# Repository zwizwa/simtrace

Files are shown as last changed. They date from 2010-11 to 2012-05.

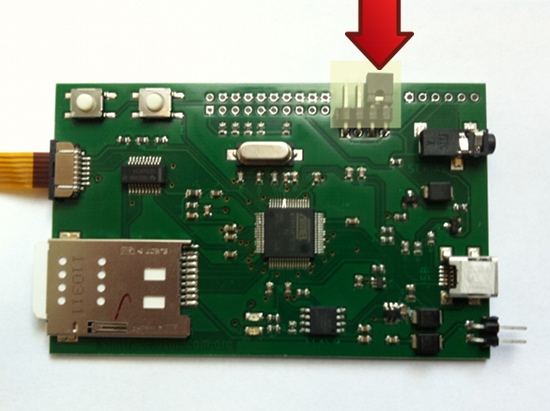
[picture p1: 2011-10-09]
docs/images/shortTEST.jpg

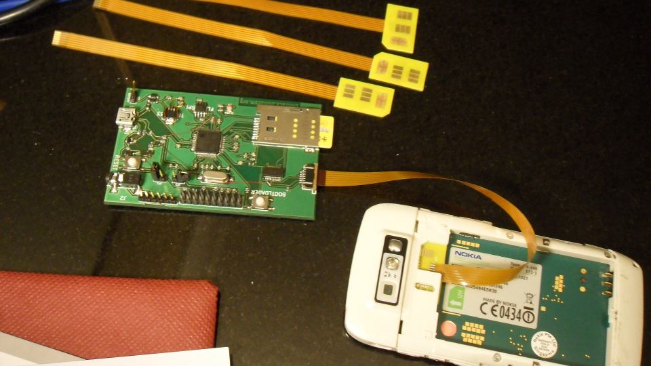
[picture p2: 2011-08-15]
docs/images/simtrace_hw_setup.png

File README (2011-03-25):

Osmocom SIMTRACE
======================================================================
(C) 2010 by Harald Welte <laforge@gnumonks.org>

SIMTRACE is a program that can be used for tracing the communication
betewen a phone and the SIM card.  More generally, it can trace any
ISO 7816 based smart card interface.

This repository contains a host program 'simtrace' as well as a patch
for wireshark.

The corresponding device firmware can be found in the openpcd.git
repository on git.gnumonks.org.

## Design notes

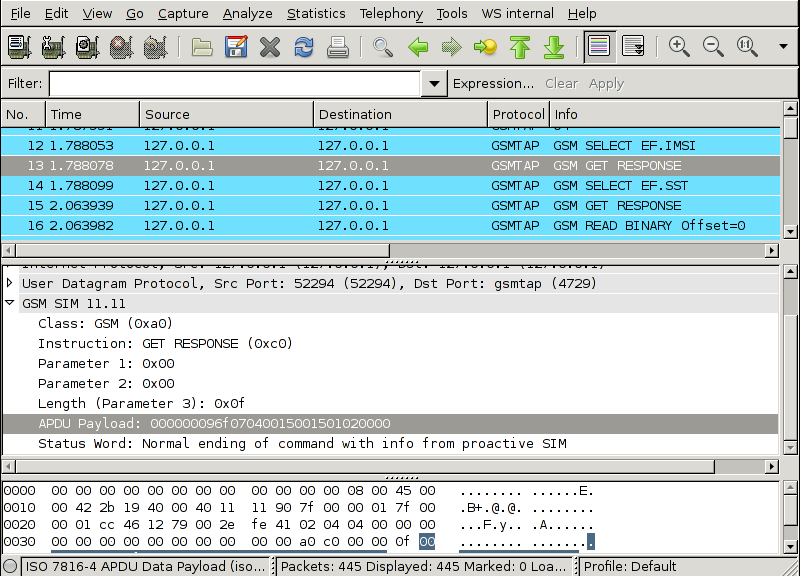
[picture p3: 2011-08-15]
docs/images/wireshark-sim.png

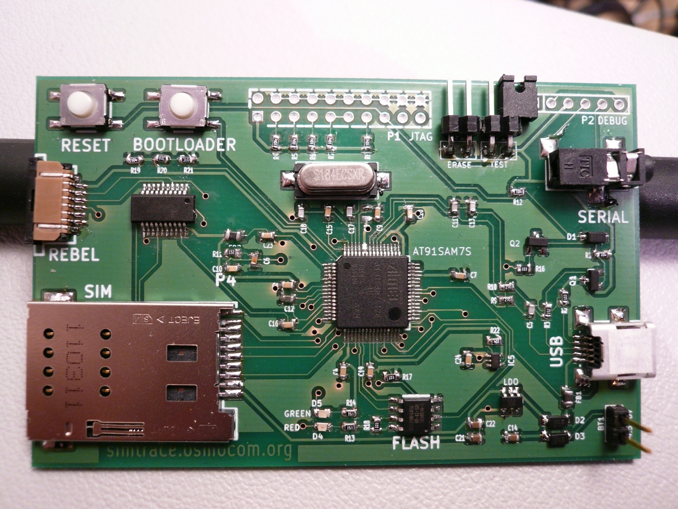
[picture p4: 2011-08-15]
docs/images/simtrace_hw.jpg

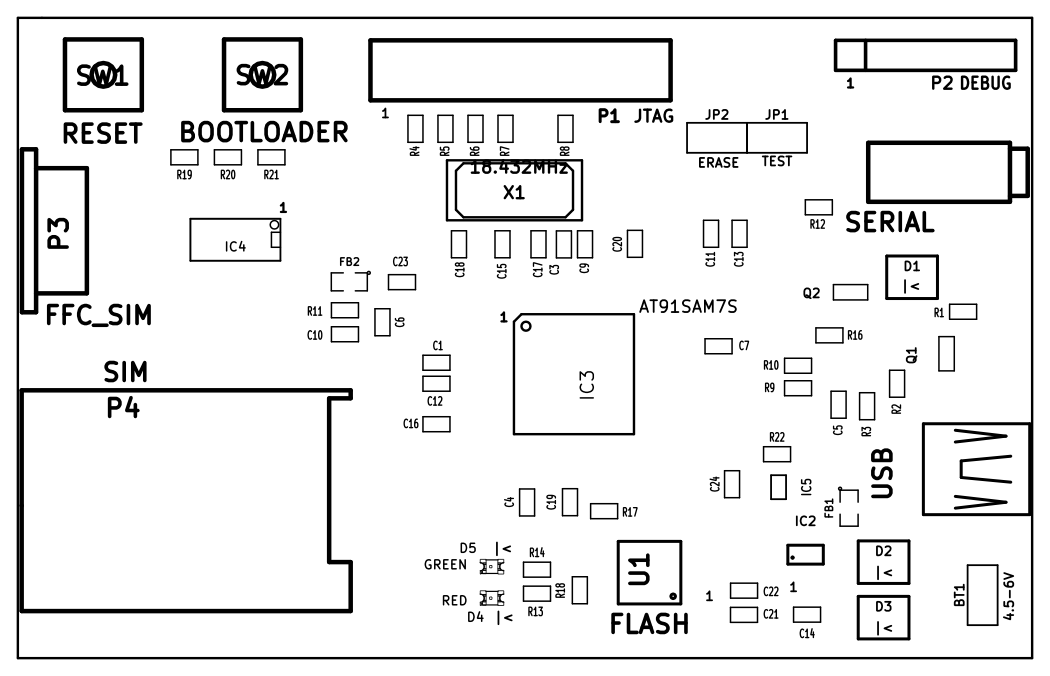
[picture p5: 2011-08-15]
docs/images/simtrace_surface.png

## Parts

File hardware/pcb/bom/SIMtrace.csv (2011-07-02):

Id | Designator | Package | Quantity | Designation | Supplier and ref
1 | P3 | FFC_REBELSIM | 1 | FFC_SIM
2 | P1 | pin_array_10x2 | 1 | JTAG
3 | JP2 | PIN_ARRAY_2X1 | 1 | ERASE
4 | JP1 | PIN_ARRAY_2X1 | 1 | TEST
5 | BT1 | PIN_ARRAY_2X1 | 1 | 4.5-6V
6 | X1 | Q_49U3HMS | 1 | 18.432MHz
7 | R18,R17,R16,R2 | SM0603 | 4 | 10K
8 | R14,R13 | SM0603 | 2 | 150R
9 | R12,R8,R7,R6,R5,R4,R1,R22,R19 | SM0603 | 9 | 100K
10 | R11,R3 | SM0603 | 2 | 1K5
11 | R10,R9 | SM0603 | 2 | 27R
12 | C23,C20,C19,C16,C15,C9,C7,C4,C3,C24 | SM0603 | 10 | 100nF
13 | C22,C21,C14 | SM0603 | 3 | 1uF
14 | C18,C17 | SM0603 | 2 | 10pF
15 | C13,C11 | SM0603 | 2 | 15pF
16 | C12,C1 | SM0603 | 2 | 2.2uF
17 | C10 | SM0603 | 1 | 1nF
18 | C6 | SM0603 | 1 | 10nF
19 | C5 | SM0603 | 1 | 33pF
20 | FB2,FB1 | SM0805 | 2 | FILTER
21 | D3,D2 | SOD123 | 2 | 1N5819
22 | D1 | SOD123 | 1 | Schottky
23 | U1 | SOIC8 | 1 | FLASH
24 | IC3 | TQFP_64 | 1 | AT91SAM7S
25 | P2 | PIN_ARRAY-6X1 | 1 | DEBUG
26 | Q2,Q1 | SOT23_BC847 | 2 | BC847
27 | SW1 | PUSH_BUTTON | 1 | RESET
28 | SW2 | PUSH_BUTTON | 1 | BOOTLOADER
29 | P4 | SIM_AMPHENOL | 1 | SIM
30 | IC4 | SSOP20_BDQ | 1 | CB3Q3244
31 | R21,R20 | SM0603 | 2 | 10k1%
32 | IC5 | SOT353 | 1 | FPF2005
33 | IC2 | SOT26 | 1 | AP7332
34 | P5 | SAM_FCI | 1 | SAM
35 | J2 | JACK2.5_SJ1-2503A | 1 | JACK_2.5
36 | J1 | USB-MINI-B_54819-0519 | 1 | USB
37 | D5 | LED-0805 | 1 | GREEN
38 | D4 | LED-0805 | 1 | RED

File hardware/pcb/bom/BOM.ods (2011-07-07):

Id | Designator | Package | Quantity | Designation | digikey ref | link
1 | P3 | FFC_REBELSIM | 1 | FFC_SIM | 609-1889-1-ND | click me
2 | P1 | pin_array_10x2 | 1 | JTAG
3 | JP2 | PIN_ARRAY_2X1 | 1 | ERASE
4 | JP1 | PIN_ARRAY_2X1 | 1 | TEST
5 | BT1 | PIN_ARRAY_2X1 | 1 | 4.5-6V
6 | X1 | Q_49U3HMS | 1 | 18.432MHz | XC1252CT-ND | click me
7 | R18,R17,R16,R2 | SM0603 | 4 | 10K | RMCF0603JT10K0CT-ND | click me
8 | R14,R13 | SM0603 | 2 | 150R | P150GCT-ND | click me
9 | R12,R8,R7,R6,R5,R4,R1,R22,R19 | SM0603 | 9 | 100K | P100KGCT-ND | click me
10 | R11,R3 | SM0603 | 2 | 1K5 | RMCF0603JT1K50CT-ND | click me
11 | R10,R9 | SM0603 | 2 | 27R | P27GCT-ND | click me
12 | C23,C20,C19,C16,C15,C9,C7,C4,C3,C24 | SM0603 | 10 | 100nF | 478-1239-1-ND | click me
13 | C22,C21,C14 | SM0603 | 3 | 1uF | 490-1543-1-ND | click me
14 | C18,C17 | SM0603 | 2 | 10pF | 490-1403-1-ND | click me
15 | C13,C11 | SM0603 | 2 | 15pF | 709-1142-1-ND | click me
16 | C12,C1 | SM0603 | 2 | 2.2uF | 478-6212-1-ND | click me
17 | C10 | SM0603 | 1 | 1nF | 478-1215-1-ND | click me
18 | C6 | SM0603 | 1 | 10nF | 490-1512-1-ND | click me
19 | C5 | SM0603 | 1 | 33pF | 490-1415-1-ND | click me
20 | FB2,FB1 | SM0805 | 2 | FILTER | P10191CT-ND | click me
21 | D3,D2 | SOD123 | 2 | 1N5819 | 1N5819HW-FDICT-ND | click me
22 | D1 | SOD123 | 1 | Schottky | MBR0530T1GOSCT-ND | click me
23 | U1 | SOIC8 | 1 | FLASH | SST25VF040B-80-4I-SAE-ND | click me
24 | IC3 | TQFP_64 | 1 | AT91SAM7S | AT91SAM7S128C-AU-ND | click me
25 | P2 | PIN_ARRAY-6X1 | 1 | DEBUG
26 | Q2,Q1 | SOT23_BC847 | 2 | BC847 | BC847CINCT-ND | click me
27 | SW1 | PUSH_BUTTON | 1 | RESET | P12943SCT-ND | click me
28 | SW2 | PUSH_BUTTON | 1 | BOOTLOADER | P12943SCT-ND | click me
29 | P4 | SIM_AMPHENOL | 1 | SIM | 101-00271-82-1-ND | click me
30 | IC4 | SSOP20_BDQ | 1 | CB3Q3244 | 296-19125-1-ND | click me
31 | R21,R20 | SM0603 | 2 | 10k1% | 311-10.0KHRCT-ND | click me
32 | IC5 | SOT353 | 1 | FPF2005 | FPF2005CT-ND | click me
33 | IC2 | SOT26 | 1 | AP7332 | AP7332-3333W6-7DICT-ND | click me
34 | P5 | SAM_FCI | 1 | SAM | 609-1414-ND | click me
35 | J2 | JACK2.5_SJ1-2503A | 1 | JACK_2.5 | CP1-2503A-ND | click me
36 | J1 | USB-MINI-B_54819-0519 | 1 | USB | WM17115-ND | click me
37 | D5 | LED-0805 | 1 | GREEN | 475-1410-1-ND | click me
38 | D4 | LED-0805 | 1 | RED | 350-2038-1-ND | click me
additional
 | FFC |  | 4 |  | WM10052-ND | click me
 | jumper |  | 2 |  | S9337-ND | click me
 | pin array 90° |  | 1 |  | S1112E-36-ND | click me

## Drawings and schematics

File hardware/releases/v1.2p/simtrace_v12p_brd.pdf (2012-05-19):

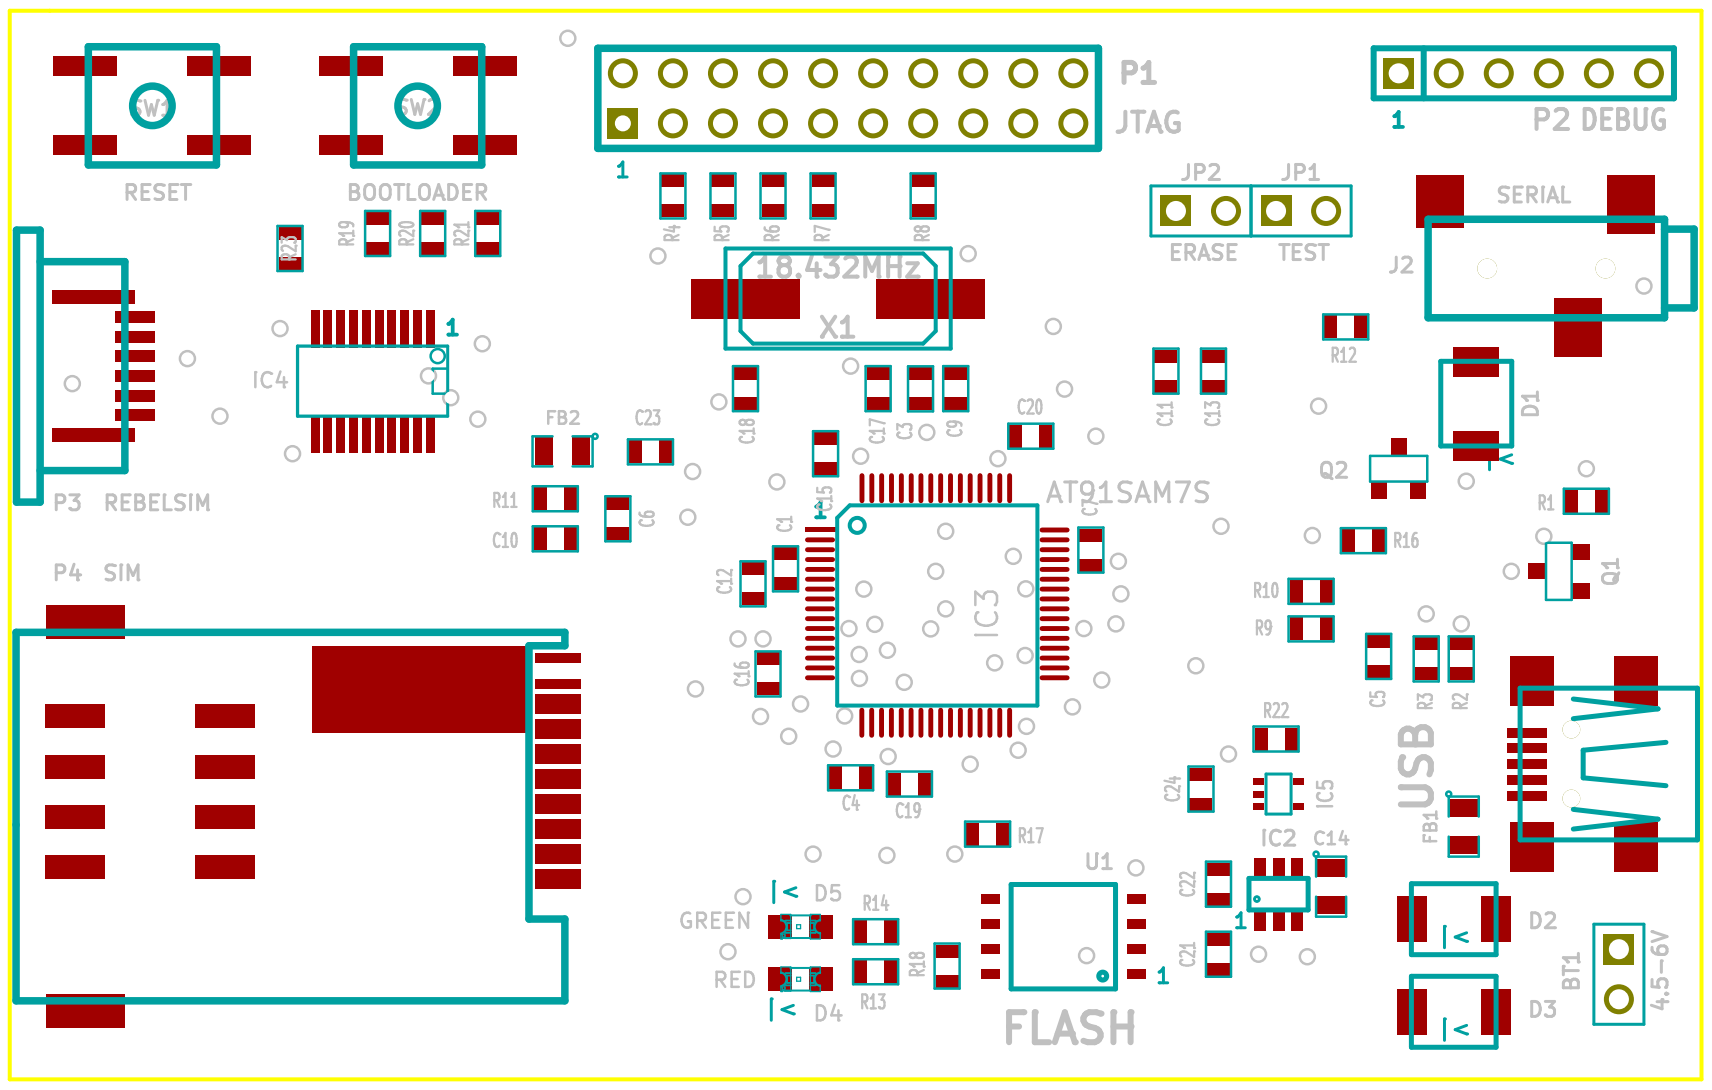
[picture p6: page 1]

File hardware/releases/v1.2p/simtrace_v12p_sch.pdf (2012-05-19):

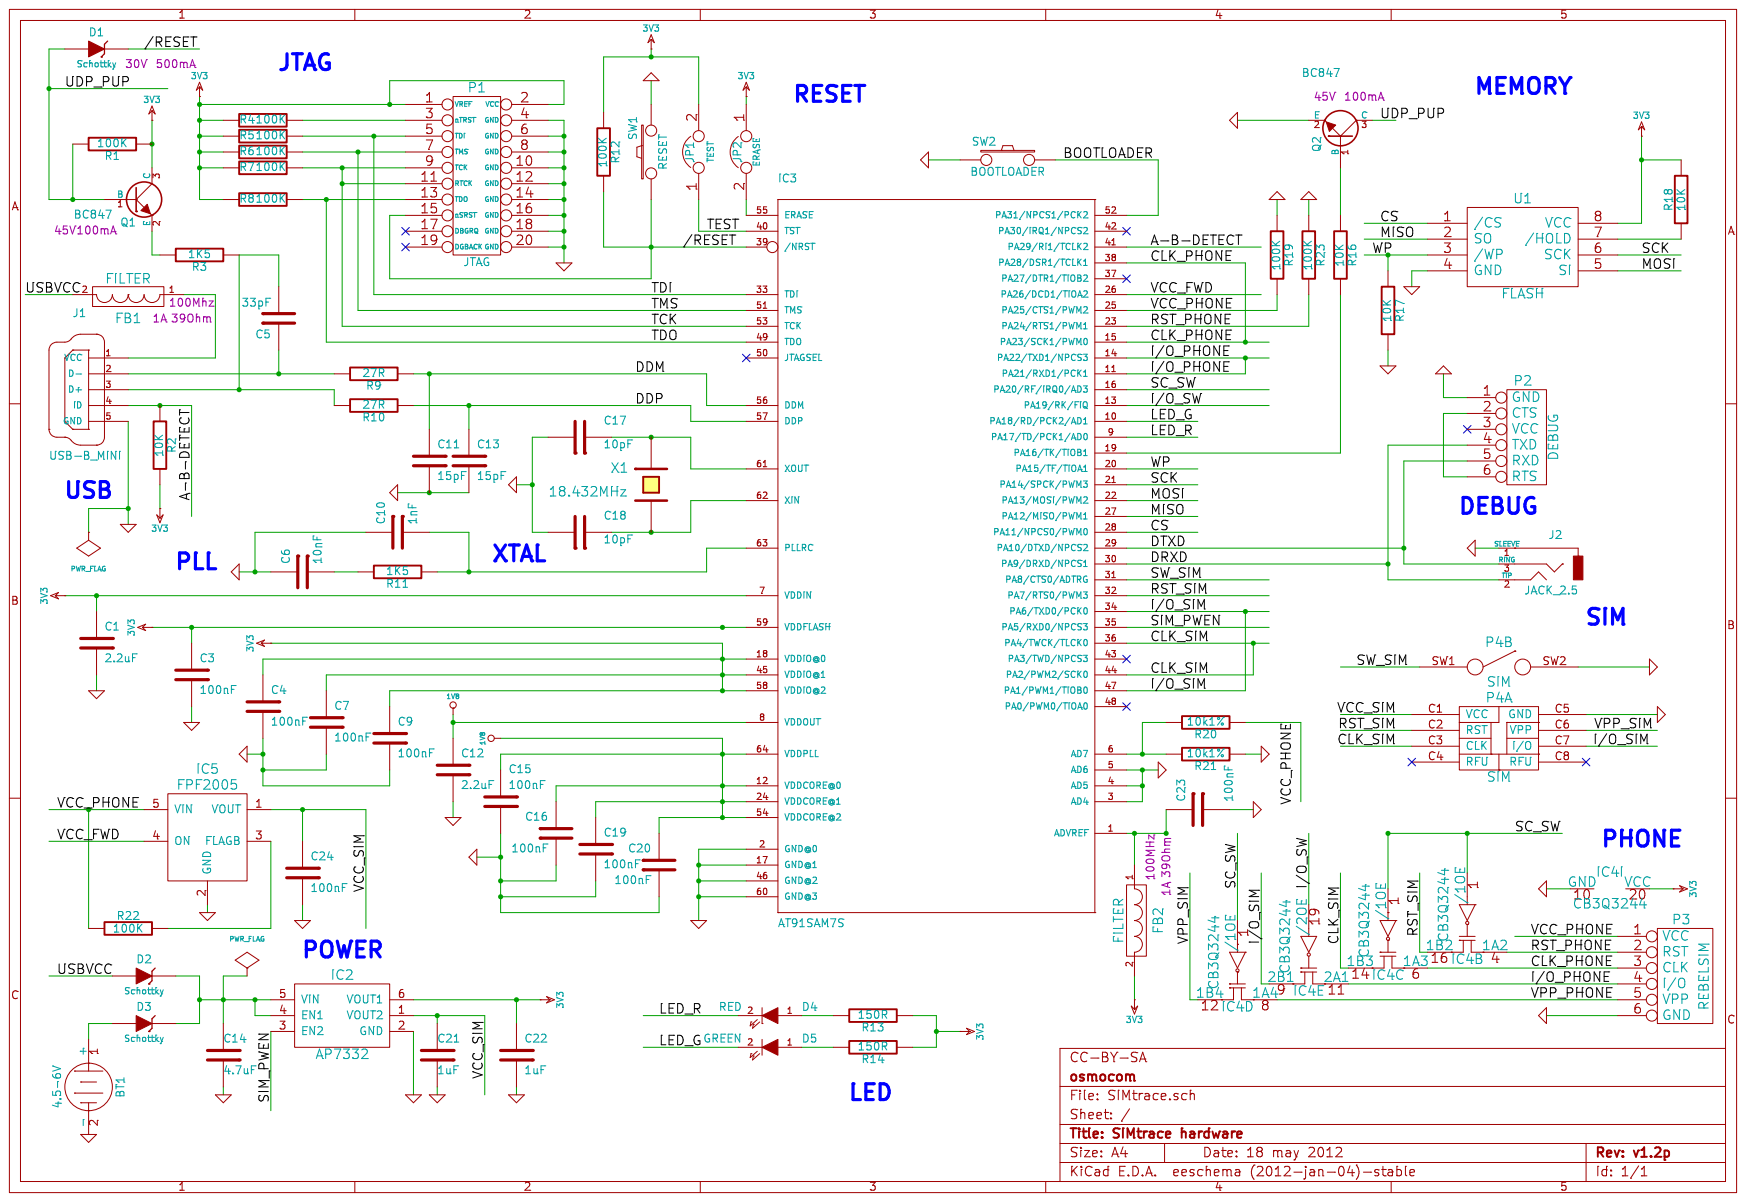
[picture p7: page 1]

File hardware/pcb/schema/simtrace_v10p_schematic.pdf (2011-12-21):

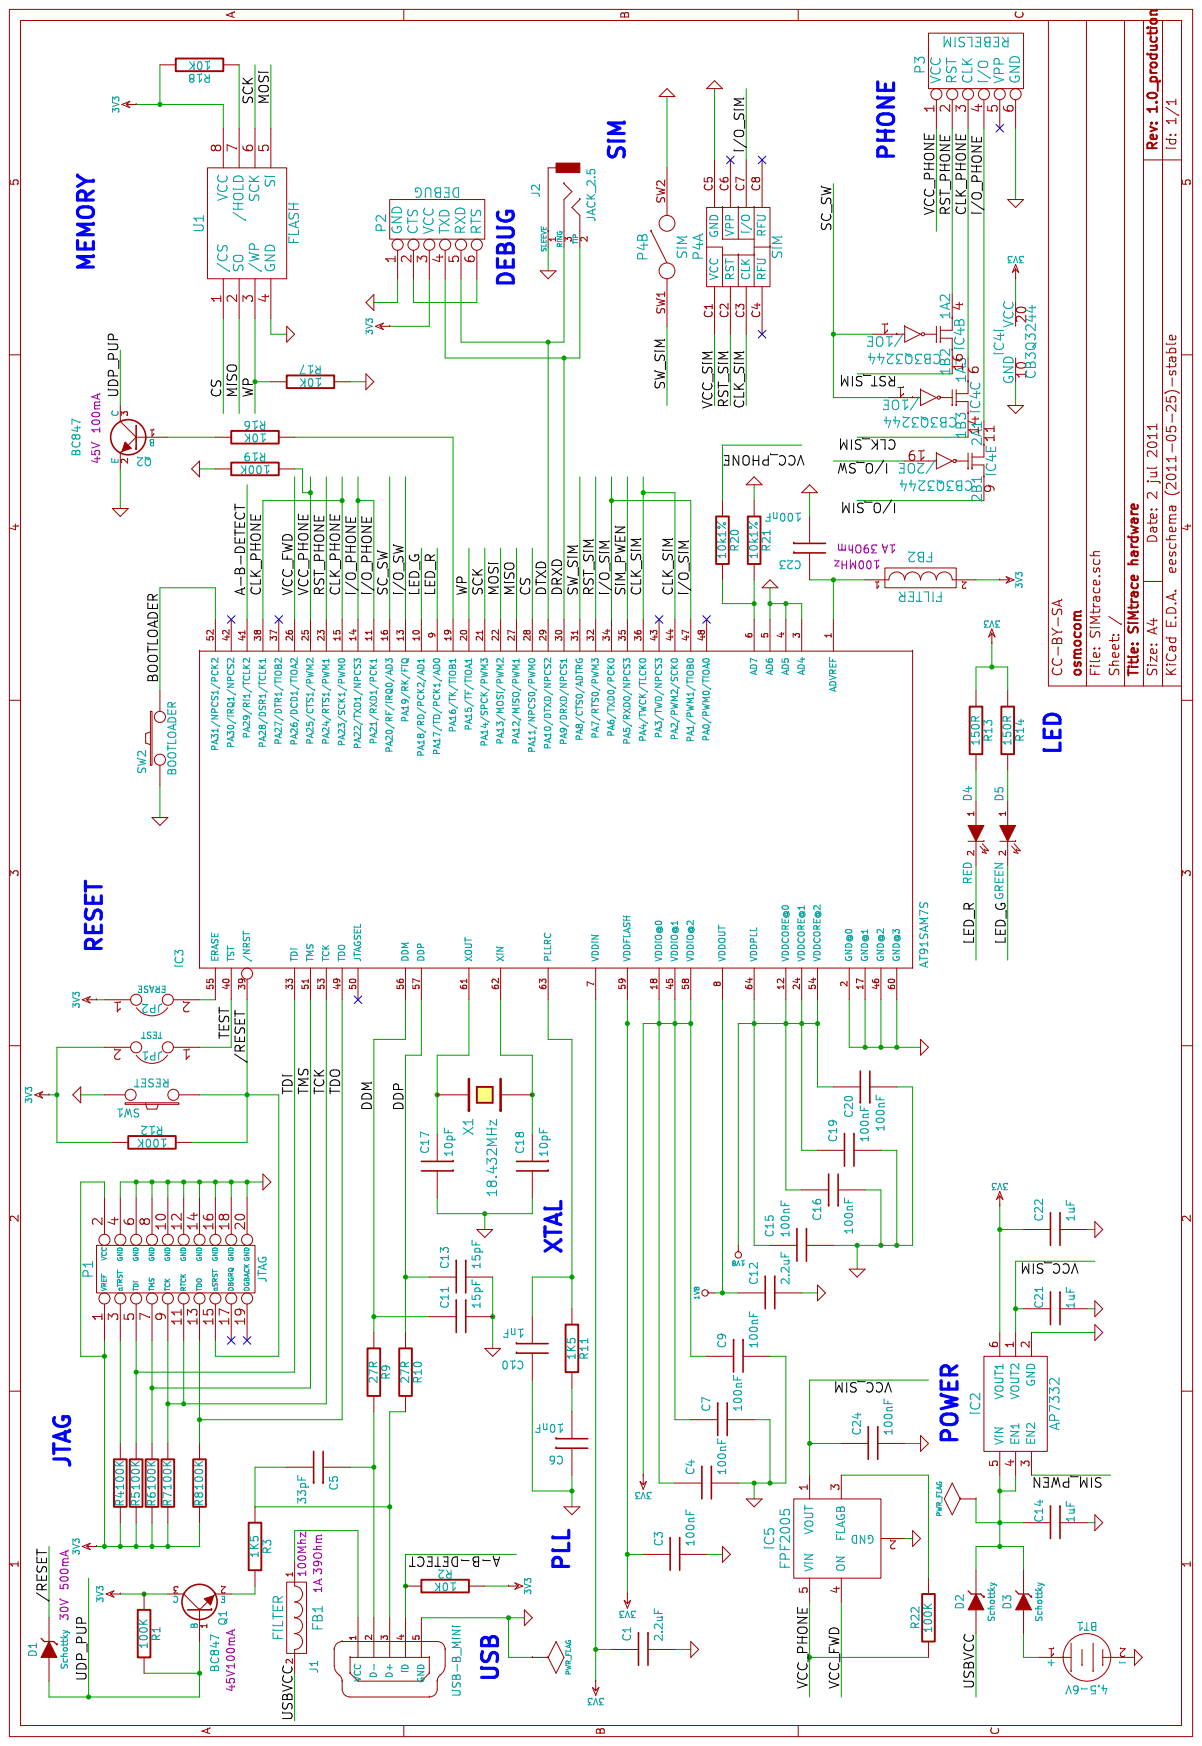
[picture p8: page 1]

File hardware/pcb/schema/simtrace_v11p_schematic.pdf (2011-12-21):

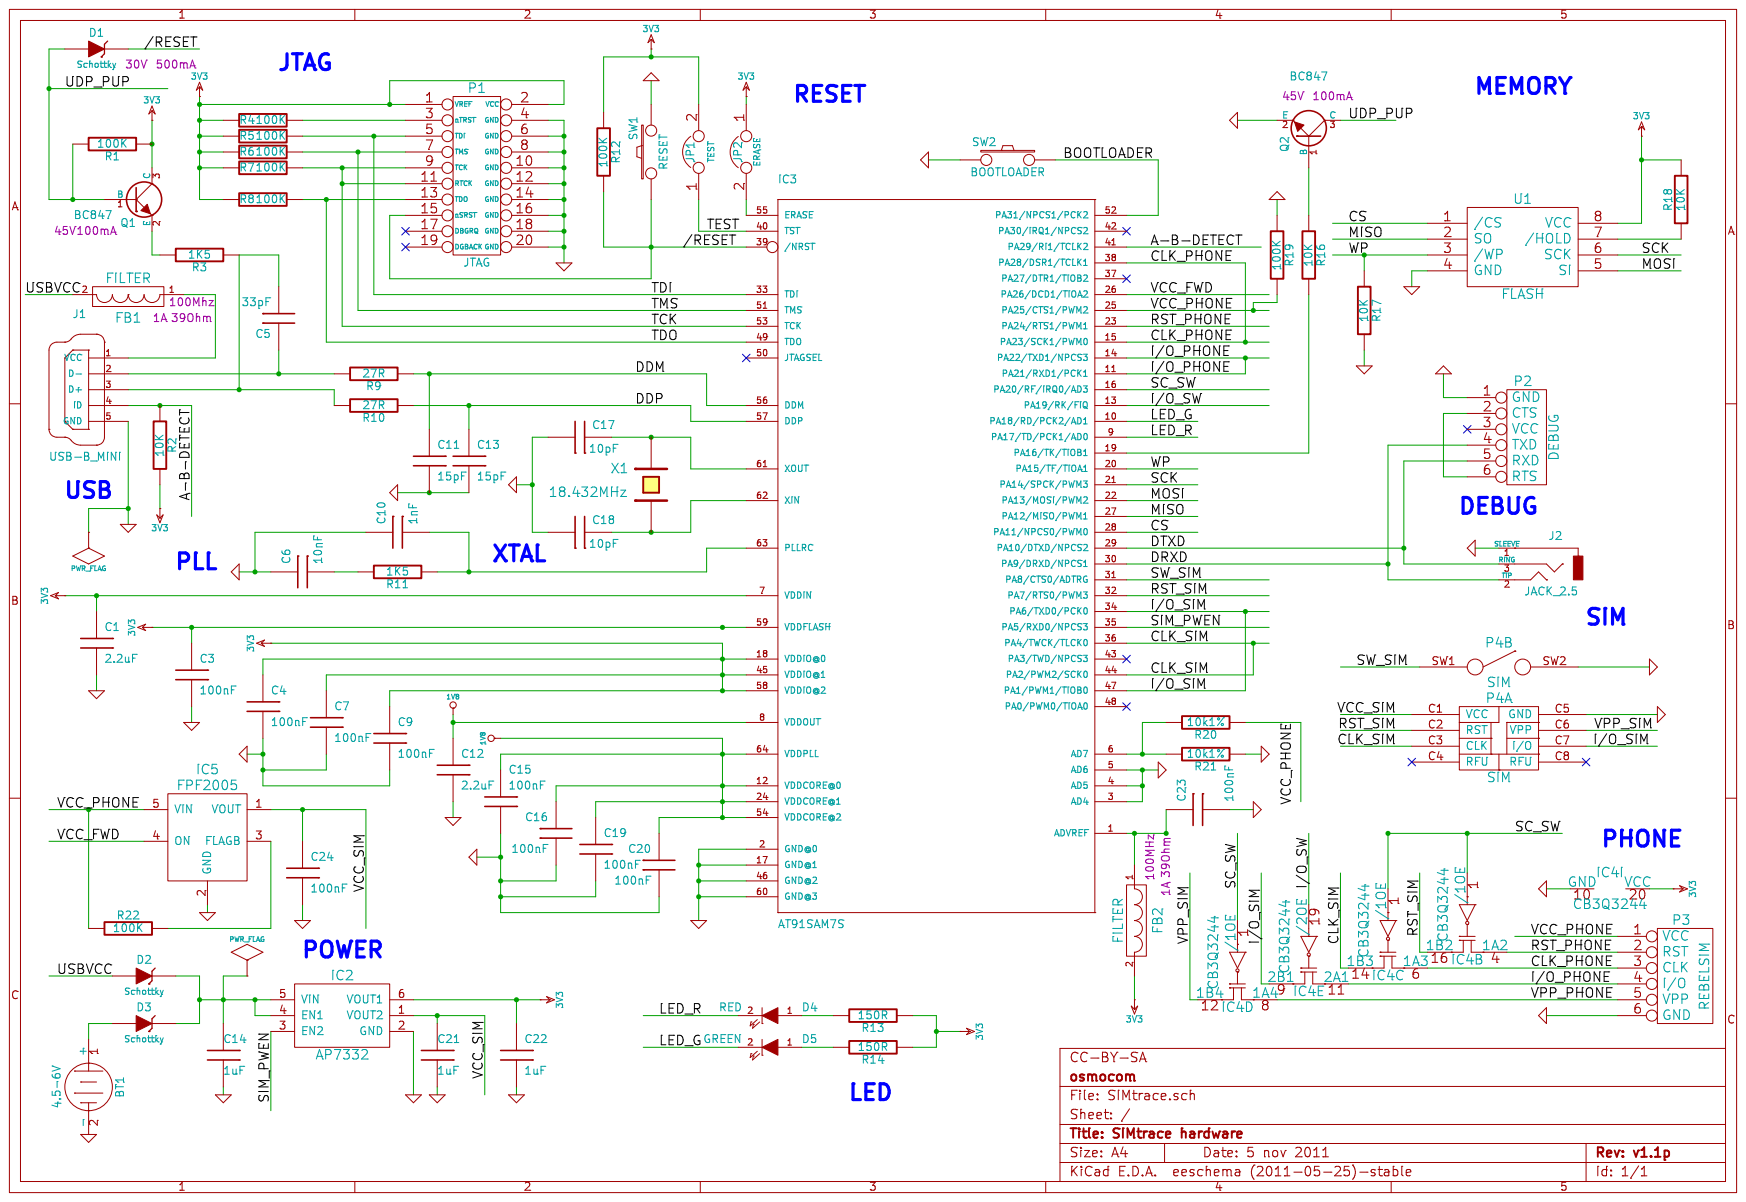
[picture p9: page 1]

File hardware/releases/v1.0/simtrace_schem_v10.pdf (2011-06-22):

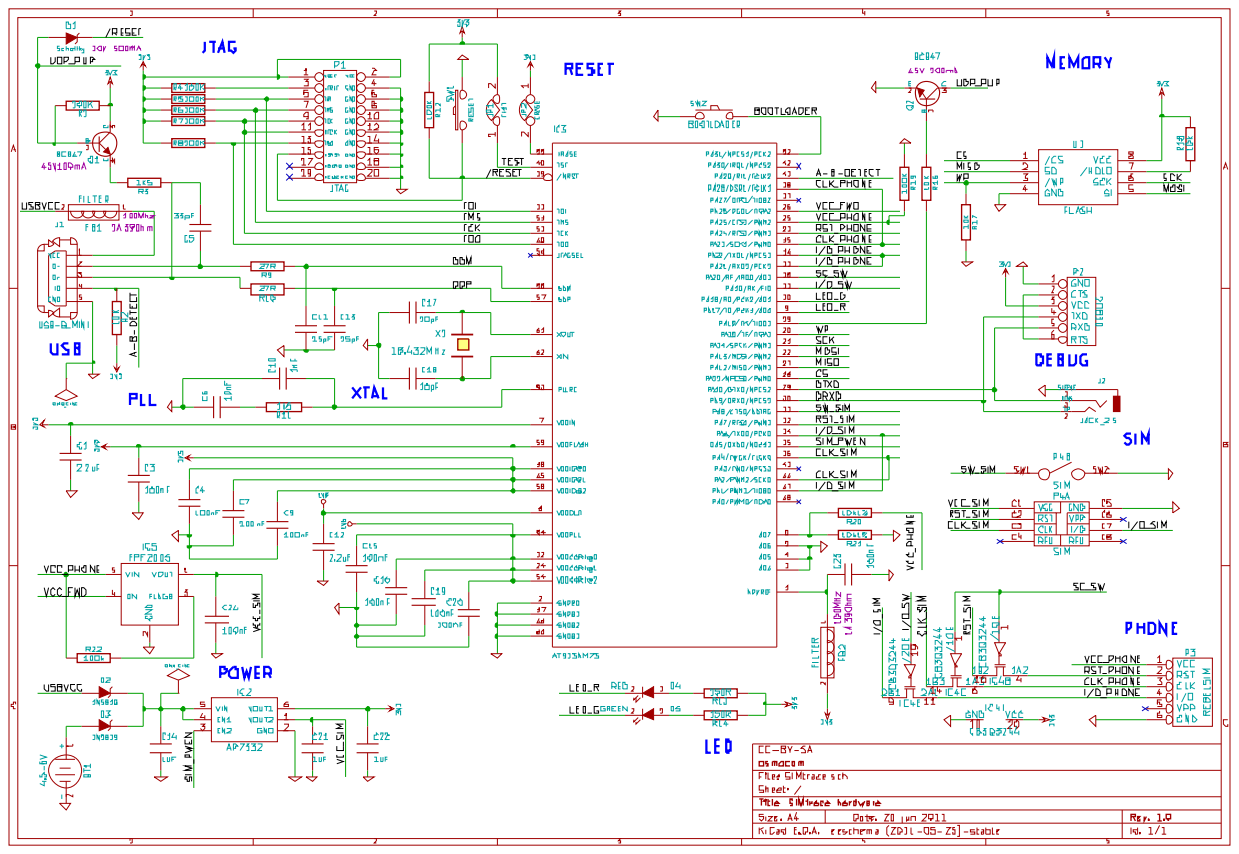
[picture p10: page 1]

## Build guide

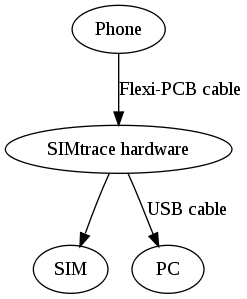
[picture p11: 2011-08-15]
docs/images/setup_overview.png

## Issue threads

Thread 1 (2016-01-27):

Question

SnakeO, 2016-01-27:
sorry if this is the wrong place to ask this but -- can I view my devices GPRS data / SMS messages as they are transmitted with this (+ the hardware)?

zwizwa, 2016-01-27:
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
no

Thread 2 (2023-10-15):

pcb payout and gerber files for sim connectors

SidBobhate, 2023-10-15:
Hi zwizwa,

Could you please add nano/micro/ full sim flex connector pcb and gerber files ?
I am based out of India to order it from sysmocom webshop is not affordable and possible as well.

Thanks in advance if you have and open to share.

zwizwa, 2023-10-15:
Please contact pll at Sysmocom. I don't have design files.

Closed 2023-10-15.

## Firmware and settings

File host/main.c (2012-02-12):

/* simtrace - main program for the host PC
 *
 * (C) 2010-2011 by Harald Welte <hwelte@hmw-consulting.de>
 *
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
 *  You should have received a copy of the GNU General Public License
 *  along with this program; if not, write to the Free Software
 *  Foundation, Inc., 59 Temple Place, Suite 330, Boston, MA  02111-1307  USA
 */

#include <errno.h>
#include <unistd.h>
#include <stdio.h>
#include <stdlib.h>
#include <string.h>
#include <stdint.h>
#include <time.h>
#define _GNU_SOURCE
#include <getopt.h>

#include <sys/time.h>
#include <sys/types.h>
#include <sys/socket.h>
#include <netinet/in.h>
#include <arpa/inet.h>

#include <libusb.h>

#include "simtrace.h"
#include "simtrace_usb.h"
#include "apdu_split.h"

#include <osmocom/core/gsmtap.h>
#include <osmocom/core/gsmtap_util.h>
#include <osmocom/core/utils.h>

static struct apdu_split *as;
static struct gsmtap_inst *g_gti;

static int gsmtap_send_sim(const uint8_t *apdu, unsigned int len)
{
	struct gsmtap_hdr *gh;
	unsigned int gross_len = len + sizeof(*gh);
	uint8_t *buf = malloc(gross_len);
	int rc;

	if (!buf)
		return -ENOMEM;

	memset(buf, 0, sizeof(*gh));
	gh = (struct gsmtap_hdr *) buf;
	gh->version = GSMTAP_VERSION;
	gh->hdr_len = sizeof(*gh)/4;
	gh->type = GSMTAP_TYPE_SIM;

	memcpy(buf + sizeof(*gh), apdu, len);

	rc = write(gsmtap_inst_fd(g_gti), buf, gross_len);
	if (rc < 0) {
		perror("write gsmtap");
		free(buf);
		return rc;
	}

	free(buf);
	return 0;
}

static void apdu_out_cb(uint8_t *buf, unsigned int len, void *user_data)
{
	printf("APDU: %s\n", osmo_hexdump(buf, len));
	gsmtap_send_sim(buf, len);
}

static int process_usb_msg(uint8_t *buf, int len)
{
	struct simtrace_hdr *sh = (struct simtrace_hdr *)buf;
	uint8_t *payload = buf += sizeof(*sh);
	int payload_len = len - sizeof(*sh);

	if (payload_len < 0)
		return -EINVAL;
	
	switch (sh->cmd) {
	case SIMTRACE_MSGT_DATA:
		/* special treatment for ATR */
		if (sh->flags & SIMTRACE_FLAG_ATR) {
			printf("ATR ");
			apdu_out_cb(payload, payload_len, NULL);
			break;
		}
		if (sh->flags & SIMTRACE_FLAG_PPS_FIDI) {
			printf("PPS(Fi=%u/Di=%u) ",
				sh->res[0], sh->res[1]);
		}
		/* everything else goes into APDU splitter */
		apdu_split_in(as, payload, payload_len);
#if 0
		/* If waiting time has expired, signal explicit boundary */
		if (sh->flags & SIMTRACE_FLAG_WTIME_EXP)
			apdu_split_boundary(as);
#endif
		break;
	case SIMTRACE_MSGT_RESET:
	default:
		printf("unknown simtrace msg type 0x%02x\n", sh->cmd);
		break;
	}
}

static void print_welcome(void)
{
	printf("simtrace - GSM SIM and smartcard tracing\n"
	       "(C) 2010 by Harald Welte <laforge@gnumonks.org>\n\n");
}

static void print_help(void)
{
	printf( "\t-i\t--gsmtap-ip\tA.B.C.D\n"
		"\t-a\t--skip-atr\n"
		"\t-h\t--help\n"
		"\t-k\t--keep-running\n"
		"\n"
		);
}

static const struct option opts[] = {
	{ "gsmtap-ip", 1, 0, 'i' },
	{ "skip-atr", 0, 0, 'a' },
	{ "help", 0, 0, 'h' },
	{ "keep-running", 0, 0, 'k' },
	{ NULL, 0, 0, 0 }
};

static void run_mainloop(struct libusb_device_handle *devh)
{
	unsigned int msg_count, byte_count = 0;
	char buf[16*265];
	int xfer_len;
	int rc;

	printf("Entering main loop\n");
	apdu_split_reset(as);

	while (1) {
		rc = libusb_bulk_transfer(devh, SIMTRACE_IN_EP, buf, sizeof(buf), &xfer_len, 100000);
		if (rc < 0 && rc != LIBUSB_ERROR_TIMEOUT) {
			fprintf(stderr, "BULK IN transfer error; rc=%d\n", rc);
			return;
		}
		if (xfer_len > 0) {
			//printf("URB: %s\n", osmo_hexdump(buf, rc));
			process_usb_msg(buf, xfer_len);
			msg_count++;
			byte_count += xfer_len;
		}
	}
}

int main(int argc, char **argv)
{
	char *gsmtap_host = "127.0.0.1";
	int rc;
	int c, ret = 1;
	int skip_atr = 0;
	int keep_running = 0;
	struct libusb_device_handle *devh;

	print_welcome();

	while (1) {
		int option_index = 0;

		c = getopt_long(argc, argv, "i:ahk", opts, &option_index);
		if (c == -1)
			break;
		switch (c) {
		case 'h':
			print_help();
			exit(0);
			break;
		case 'i':
			gsmtap_host = optarg;
			break;
		case 'a':
			skip_atr = 1;
			break;
		case 'k':
			keep_running = 1;
			break;
		}
	}

	rc = libusb_init(NULL);
	if (rc < 0) {
		fprintf(stderr, "libusb initialization failed\n");
		goto close_exit;
	}

	g_gti = gsmtap_source_init(gsmtap_host, GSMTAP_UDP_PORT, 0);
	if (!g_gti) {
		perror("unable to open GSMTAP");
		goto close_exit;
	}
	gsmtap_source_add_sink(g_gti);

	as = apdu_split_init(&apdu_out_cb, NULL);
	if (!as)
		goto release_exit;

	do {
		devh = libusb_open_device_with_vid_pid(NULL, SIMTRACE_USB_VENDOR, SIMTRACE_USB_PRODUCT);
		if (!devh) {
			fprintf(stderr, "can't open USB device\n");
			goto close_exit;
		}

		rc = libusb_claim_interface(devh, 0);
		if (rc < 0) {
			fprintf(stderr, "can't claim interface; rc=%d\n", rc);
			goto close_exit;
		}

		run_mainloop(devh);
		ret = 0;

		libusb_release_interface(devh, 0);
close_exit:
		if (devh)
			libusb_close(devh);
		if (keep_running)
			sleep(1);
	} while (keep_running);

release_exit:
	libusb_exit(NULL);
	return ret;
}

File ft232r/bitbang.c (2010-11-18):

/* This program is distributed under the GPL, version 2 */

#include <stdio.h>
#include <unistd.h>
#include <string.h>
#include <ftdi.h>

#include "soft_uart.h"

static unsigned char last;
static struct suart_data su;

#define CLK_BIT	0x20
#define RST_BIT	0x08
#define IO_BIT	0x02

static void handle_sample(unsigned char c)
{
	uint8_t rst = 0, io = 0, clk = 0;

	if (c & RST_BIT)
		rst = 1;

	if (c & CLK_BIT)
		clk = 1;

	if (c & IO_BIT)
		io = 1;

#if 0
	if ((c & 0xf) != last) {
		printf("%02x ", c & ~(CLK_BIT|IO_BIT)); 
	}
	last = c;
#endif
#if 0
	if (c & RST_BIT)
		printf("-");
	else
		printf("_");
#endif
#if 1
	if (c & IO_BIT)
		printf("-");
	else
		printf("_");
#endif
	//suart_process_sample_bit(&su, clk, rst, io);
}

#define OVERSAMPLING 4

int main(int argc, char **argv)
{
    struct ftdi_context ftdic;
    int f,i;
    unsigned char buf[1<<16];
	//unsigned int sample_rate = 12900 * OVERSAMPLING; /* 192kS/s */
	unsigned int sample_rate = (1 << 18);

	memset(&su, 0, sizeof(su));

    if (ftdi_init(&ftdic) < 0)
    {
        fprintf(stderr, "ftdi_init failed\n");
        return EXIT_FAILURE;
    }

    f = ftdi_usb_open(&ftdic, 0x0403, 0x6001);

    if (f < 0 && f != -5)
    {
        fprintf(stderr, "unable to open ftdi device: %d (%s)\n", f, ftdi_get_error_string(&ftdic));
        exit(-1);
    }

    printf("ftdi open succeeded: %d\n",f);

    printf("enabling bitbang mode\n");
    //ftdi_disable_bitbang(&ftdic);
    //ftdi_set_line_property(&ftdic, 8, 1, EVEN);
    ftdi_set_bitmode(&ftdic, 0x0, BITMODE_BITBANG);
    ftdi_read_data_set_chunksize(&ftdic, sizeof(buf));
    ftdi_set_latency_timer(&ftdic, 255);
    //ftdi_set_latency_timer(&ftdic, 1);
    //f = ftdi_set_baudrate(&ftdic, 300000);
    f = ftdi_set_baudrate(&ftdic, sample_rate/16);
    if (f < 0) {
	fprintf(stderr, "error setting baudrate\n");
	exit(1);
    }

	su.samplerate = sample_rate;
	su.recip_etu = sample_rate / OVERSAMPLING;
	su.num_bits = 8;
	suart_init(&su);

    while (1) {
	memset(buf, 0, sizeof(buf));
	f = ftdi_read_data(&ftdic, buf, sizeof(buf));
        if (f < 0) {
		fprintf(stderr,"read failed for 0x%x, error %d (%s)\n",buf[0],f, ftdi_get_error_string(&ftdic));
		exit(1);
        }
	//printf("ftdi returned %u (of %u)\n", f, sizeof(buf));
	for (i = 0; i < f; i++) {
		handle_sample(buf[i]);
	}
	fflush(stdout);
	//num_samples += f;
    }

    printf("\n");

    printf("disabling bitbang mode\n");
    ftdi_disable_bitbang(&ftdic);

    ftdi_usb_close(&ftdic);
    ftdi_deinit(&ftdic);
}

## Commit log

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2010-11-18 Import old unfinished FT232R bit-banging code for sim sniffing
    This code never really worked due to large sample clock jitter, lost
    USB messages and the lack of CLK sniffing ability
    [bitbang.c, soft_uart.c]
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2011-05-13 import simtrace hardware v0.1
    [trac.brd, trac.sch]
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2011-05-13 update to SIMtrac v0.2
    [SIMtrac.sch]
2011-05-13 hardweare: update schematics to simtrace v0.3
    [SIMtrac.sch]
2011-05-13 update simtrace schematics to 0.4
    [SIMtrac.sch]
2011-05-13 rename from SIMtrace to SIMtrace
    [SIMtrace.brd, SIMtrace.sch]
2011-05-13 Update kicad project to SIMtrace v0.5
    [SIMtrace.sch]
2011-05-13 Update kicad project to v0.6
    [SIMtrace.sch]
2011-05-13 update kicad project to v0.7
    [SIMtrace.sch]
2011-05-13 update kicad project to v0.7+
    [SIMtrace.sch]
2011-05-13 update kicad project to v0.8
    [SIMtrace.sch]
2011-05-13 update kicad project to v0.9
    [SIMtrace.sch]
2011-05-13 update kicad project to v0.9+
    [SIMtrace.brd, SIMtrace.csv, SIMtrace.sch]
2011-05-15 kevin local new versin enforced
    [SIMtrace.brd, SIMtrace.csv, SIMtrace.sch]
2011-05-15 pcb drawings & gerber added
    [BOM.ods, SIMtrace.csv, SIMtrace.dsn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]
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2011-06-15 BC847 footprint corrected
    [SIMtrace.brd, SIMtrace.sch]
2011-06-15 switch footprint corrected
2011-06-15 switch routing corrected
    [SIMtrace.brd]
2011-06-15 UDP_PUP now connected to PA16 (pin 19) on schema
    [SIMtrace.brd, SIMtrace.sch]
2011-06-15 USB_PUP all whole board rerouted
    [SIMtrace.dsn]
2011-06-15 better route for sw2
    [SIMtrace.brd]
2011-06-15 second gnd added for TPS73633
    [SIMtrace.brd, SIMtrace.sch]
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2011-06-17 component name moved, pin 1 marked
    [SIMtrace.brd]
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2011-06-19 SIM_SW connected to GND, components moved
    [SIMtrace.brd, SIMtrace.sch]
2011-06-19 VCC_PHONE connected to GPIO
    [SIMtrace.brd, SIMtrace.sch]
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2011-06-20 USB changed, BOM updated
    [BOM.ods, SIMtrace.brd]
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2011-06-20 bus switch CB3q3244 used instead of QS3244
    [BOM.ods, SIMtrace.brd, SIMtrace.sch]
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2011-06-20 better ADC, LDO changed
    [SIMtrace.sch]
2011-06-20 LDO, and power switch added. not verified yet
    [BOM.ods, SIMtrace.brd, SIMtrace.sch]
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2011-06-21 VCC track increased, name added
    [SIMtrace.brd]
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2011-06-21 antenna logo to put on the PCB, but it's not used because there is an unknown cleareance issue when filling the area : the picture is partially masked
2011-06-21 rebelSIM PCB SIM card for FFC (flat flexible cable) schema created. we could produce our own
    [simcable.sch]
2011-06-21 wrong USB connector from digikey in BOM chosen. corrected : hirose UX60-MB-5ST / digikey H2959CT-ND
    [BOM.ods]
2011-06-21 v1.0 released. board version added, output (schema,gerber) rendered
    [SIMtrace-Back.gbl, SIMtrace-Drawings.gbr, SIMtrace-Front.gtl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]
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2011-06-22 thermal pads were missing on the bottom layer on the PCB in kicad
    [SIMtrace.brd]
2011-06-22 ps/gerber rerendered for the thermal footprints
    [SIMtrace-Back.gbl, SIMtrace-Drawings.gbr, SIMtrace-Front.gtl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]
2011-06-23 PCB PS drawings were in the wrong folder
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2011-07-01 simcable pcb drawing created. only the footprints have been placed
    [simcable.brd]
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2011-07-01 ID1 slot (named SAM, even if not entirely correct) added in schema (now v1.1)
    [SIMtrace.sch]
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2011-07-01 netlist now include the SAM slot
    [SIMtrace.sch]
2011-07-01 SJ1-2503A replaces SJ-2523-SMT for the jack 2.5mm connector. it's now throughole for more robustness
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2011-07-01 MOLEX 54819-0519 will replace HIROSE UX60-MB-5ST for USB mini-B connector. it's now throughole for more robustness
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2011-07-01 new USB and jack 2.5 footprint used in the schema. netlist and component list generated
    [SIMtrace.sch]
2011-07-01 BOM updated. new SAM (FCI 52400-25ALF), USB (molex 54819-0519), Jack 2.5mm (CUI SJ1-2503A) added and linked
    [BOM.ods, SIMtrace.csv]
2011-07-01 components updated (pads are not on both sides); components placed; only the USB+power distribution routing has been done (by hand)
    [SIMtrace.brd]
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2011-07-01 component names and comment (pin 1, diode) placed on silk screen
    [SIMtrace.brd]
2011-07-01 shema/board/gerber generated. v1.1 released (untested)
    [SIMtrace-Back.gbl, SIMtrace-Comments.gbr, SIMtrace-Drawings.gbr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]
2011-07-02 simcable is now a set of 4 SIM cards with FFC pads. Schema and PCB done
    [simcable.brd, simcable.sch]
2011-07-02 schema/PCB/gerber output for simcable generated
    [simcable.brd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]
2011-07-02 LED now uses 0805 footprint instead of 0603
    [SIMtrace.brd, SIMtrace.sch]
2011-07-02 BOM updated for LED (0805)
    [BOM.ods, SIMtrace.csv]
2011-07-07 button are now harder to press (50gf vs 130gf)
    [BOM.ods]
2011-07-07 flex board sim cables created (pcb edge are wrong)
    [simffc.brd, simffc.sch]
2011-07-07 connection rounded (2.0mm radius) and copper added
    [simffc.brd]
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2011-08-13 cap near cpu, routing improved
    [SIMtrace.brd]
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2011-08-15 Silence warning: initialization from incompatible pointer type
    [main.c]
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2011-08-16 wireshark: Add one more missing file
2011-10-26 switched from KiCAD to gEDA (scriptable), SAM3S replaces SAM7S, no PLLRC required, 2.2uF cap replaces 1uF for less different components, uSD slot replaces flash
    [simtrace.sch]
2011-10-26 cap placed near to CPU, some tracks redrawn
    [SIMtrace.brd]
2011-10-31 simffc: make sure PCB edges really are on the edge, not on Eco2 layer
    [simffc.brd]
2011-11-05 schema boxes, cb3q3244 redraw more schematic, uSD slot added, rakefile support adding version
    [simtrace.sch]
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2011-11-13 hw: LDO LP2966 replaces AP7332, +1.8V from LDO is used for AT91SAM3S VDDCORE/VDDPLL instead of VDDOUT
    [simtrace.sch]
2011-11-13 hw: power switch replaced: FPF2005 to FPF2300
    [simtrace.sch]
2011-11-13 hw: inverted pin name corrected
2011-11-13 hw: power selector implemented (demultiplexer + inverer + power switch)
    [simtrace.sch]
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2011-11-29 hw: SIM FFC cables gerber exported. only ppa/paxer kicad could open pcb \!\!\!
    [simffc-Front.gtl, simffc-Mask_Front.gts, simffc-PCB_Edges.gbr]
2011-12-01 hw: LDO changed(now using multiple TP1071), PWR lines remaned according to classes
    [simtrace.sch]
2011-12-07 hw: SIM card is smaller (14.9mm instead of 15mm) to better fit in the slot
    [simffc.brd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]
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2011-12-14 FFC: add "sysmocom" text on copper layer of all four adapters
    [simffc.brd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]
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2011-12-14 main: Move code around to let the SIMtrace keep running...
    Re-open the USB device, reset the state... handle reconnects of
    the device.
    [main.c]
2011-12-15 FFC: add edges of stiffener to Eco1 layer
    [simffc.brd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]
2011-12-26 hw: power selector for phone removed. only VCC_PHONE is needed
    [simtrace.sch]
2011-12-26 hw: only 2 adjustable LDOs are used. 1x3.3v for CPU, 1 for the SIM
    [simtrace.sch]
2011-12-26 hw: input voltage attached to ADC, so to measure max SIM voltage output
    [simtrace.sch]
2011-12-26 hw: +1.8V output corrected, as it does not exist
    [simtrace.sch]
2011-12-29 hw: power sources path corrected
    [simtrace.sch]
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2013-06-12 add GEDA and gerber data for microSIM (3FF) adapter cable
    Original by Kevin Redon, layout improvements by myself.
    [mini-UICC.outline.gbr, mini-UICC.stiffener.gbr, mini-UICC.top.gbr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]

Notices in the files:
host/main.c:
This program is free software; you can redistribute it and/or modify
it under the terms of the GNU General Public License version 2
